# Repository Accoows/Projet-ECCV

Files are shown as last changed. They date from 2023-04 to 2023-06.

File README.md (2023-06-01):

Ce projet est réalisé dans le cadre du module Communication Sans Fil en Licence 1 à l’Université
Nice Sophia Antipolis.

Le projet a été réalisé en groupe avec 3 personnes : Jules; Arthur; Alec

# Projet-ECCV

ProjetECCV

# Description du projet

Il s'agit de créer une voiture télécommandée contrôlée par un smartphone grâce à une application. L'application utilisée, appelée "Blynk", est disponible sur les plateformes IOS et Android. L'utilisateur peut utiliser des sliders pour contrôler les moteurs à l'avant de la voiture, en les déplaçant vers l'avant ou l'arrière individuellement.

L'objectif est d'obtenir une portée de signal supérieure à 20 mètres en utilisant une connexion serveur via 4G entre le système embarqué de la voiture et le smartphone. Cette liaison permettra au smartphone de contrôler la voiture à distance et d'établir une communication fiable sur une distance étendue. Le smartphone envoie les données à un serveur Blynk, qui les transmet ensuite à la carte Wi-Fi pour activer les moteurs. Un système d'historique de connexion est intégré pour suivre la durée pendant laquelle l'engin reste connecté.

BlynkExample

# Matériel utilisé

### Pour réaliser l'engin chenillé, vous aurez besoin des éléments suivants :
- x1 Carte ESP8266 NodeMCU Amica V2 (ESP-12F)
- x1 Un Pont H L298N
- x1 Une breadboard (Cable management)
- x1 Une batterie externe
- x1 Support de piles 12V
- x2 Moteur DC - 12V
- Caisse - Impression 3D
- Roues et Chenilles - Impression 3D
- Des fils
- Du polystyrène

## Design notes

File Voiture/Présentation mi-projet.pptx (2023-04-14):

## Engin CHENILLé CAMPUS VALROSE Présentation de mi-parcours

- Arthur Gonzales
- Alec Passolunghi
- Jules Roy
UE ELECTRONIQUE S2 : Communication sans fil

1

## Objectif du projet

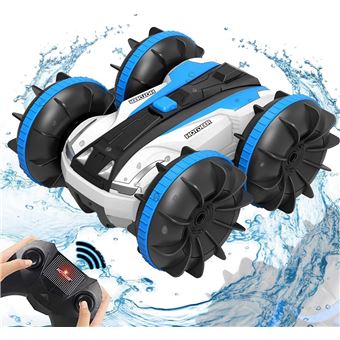
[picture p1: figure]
Voiture Télécommandée Amphibie, Véhicule de Course de Jouet à Haute Vitesse 2.4GHz 4WD, Rotation à 360 degrés, （Bleu） - Voiture télécommandée - Achat & prix | fnac
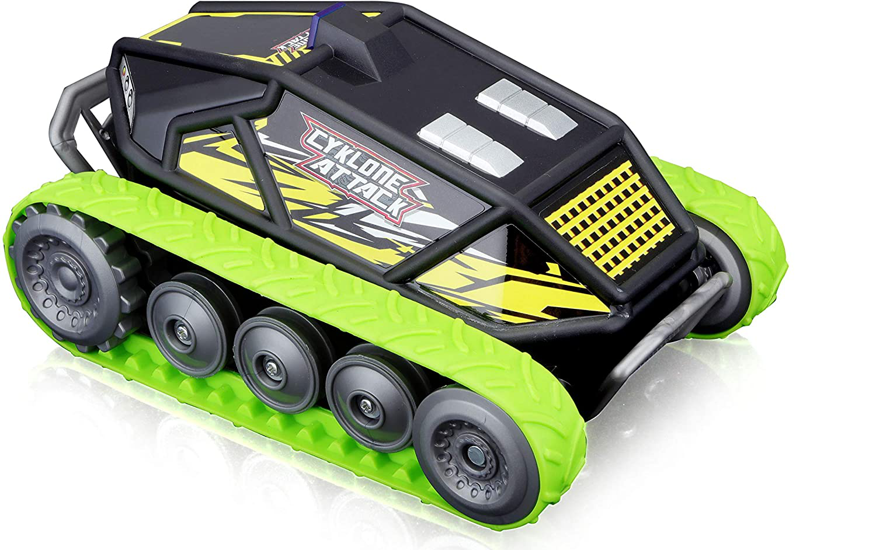
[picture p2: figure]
Bburago Maisto France Véhicule radiocommandé à Chenille Tread Shredder 27 MHz : Amazon.fr: Jeux et Jouets

2

## Répartition des taches et planning

Alec
Modélisation
Arthur
Budget
Programmation
Jules
Documentation
À attribuer
Assemblage
Impression des pièces

14 Avril
Présentation de Mi-projet
Fin Avril
Réception des pièces
30 Mai
Présentation projet final
Montage
Mi Mai
Impression des pièces 3D
Début Mai
Programmation

3

## Résultat attendu

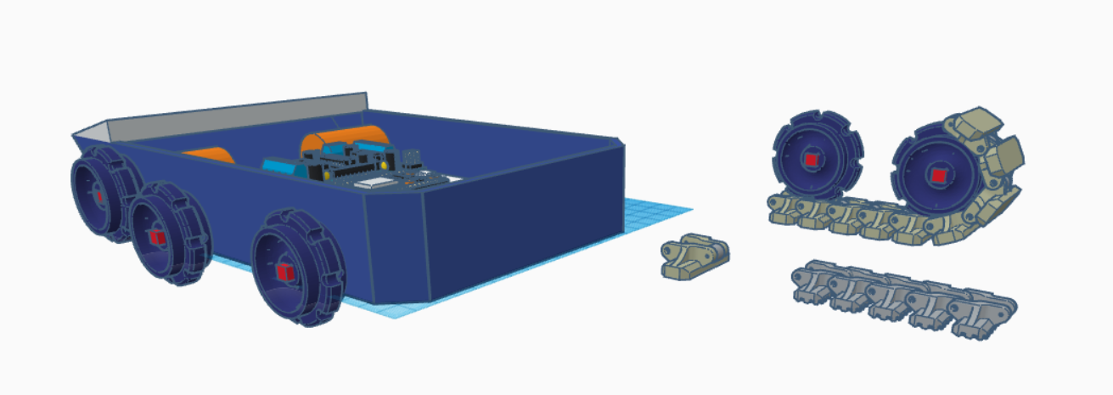
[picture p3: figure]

4

## Méthode de réalisation

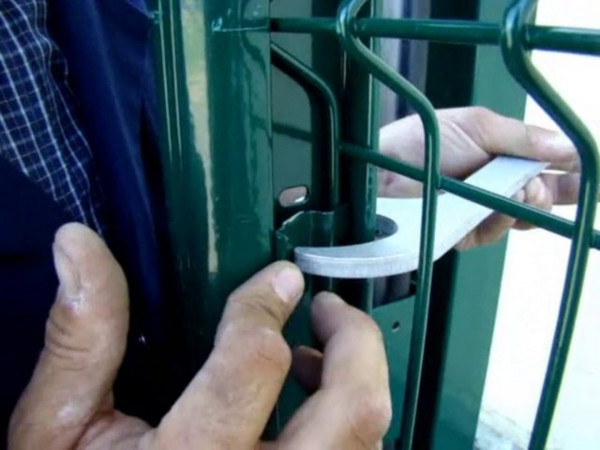
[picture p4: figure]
Clé à Clips, idéal pour le montage de vos clôtures| CLÔTUR-ECO - Clôtur-Éco
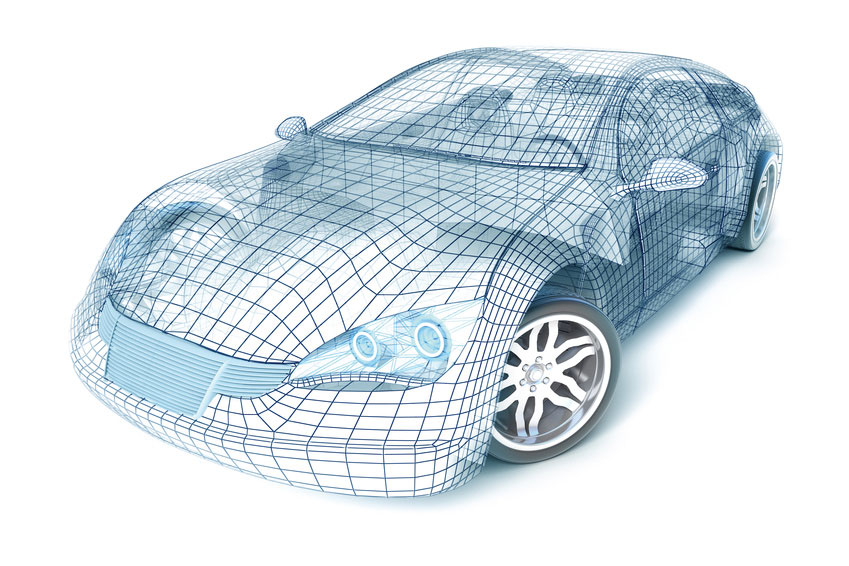
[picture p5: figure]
Comment choisir un logiciel de modélisation 3D ? - F3DF
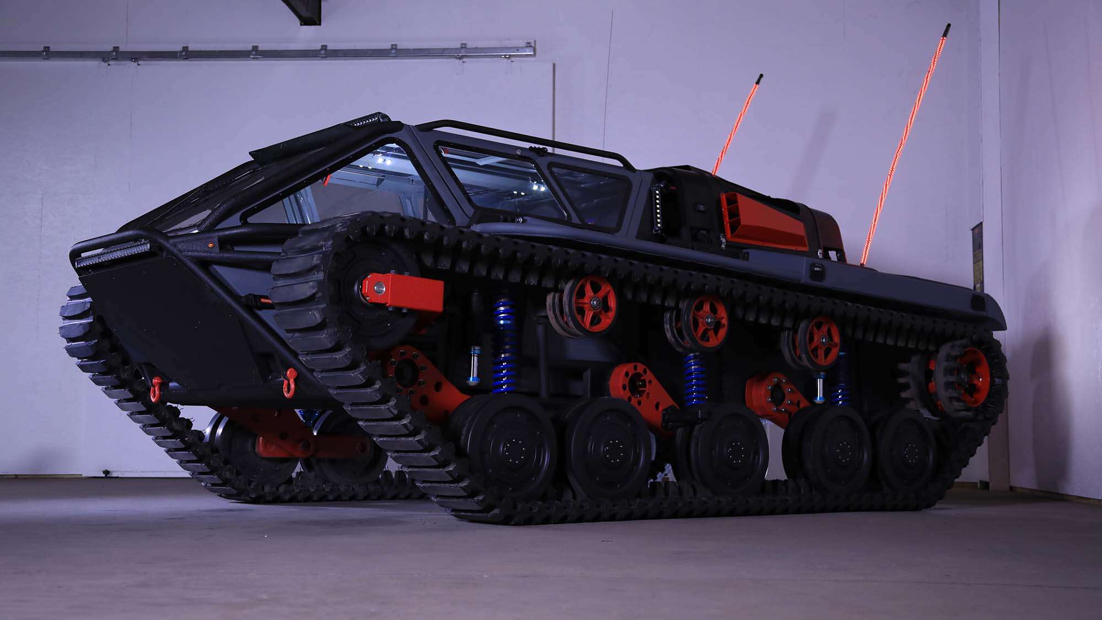
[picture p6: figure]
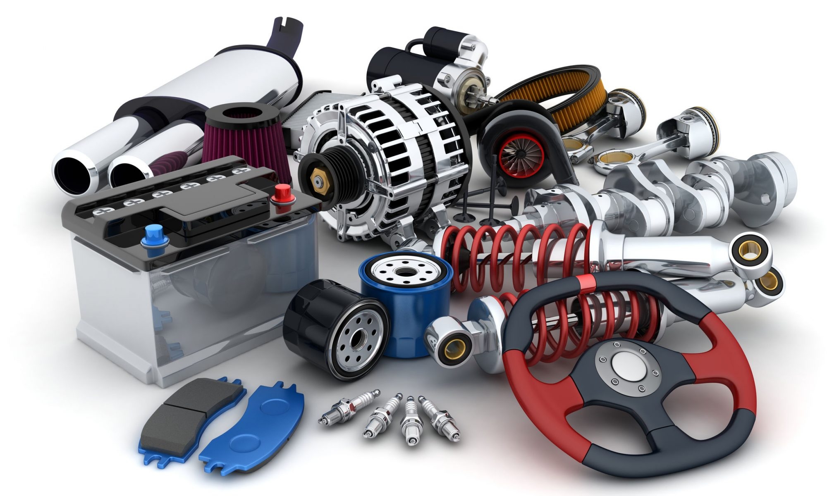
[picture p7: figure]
Enquête - Pièces autos : comment bien les choisir en évitant les pièges
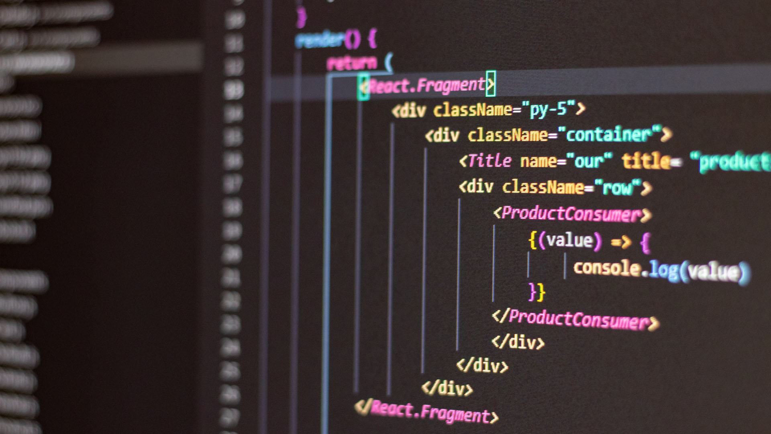
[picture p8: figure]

5

## Moyens nécessaires

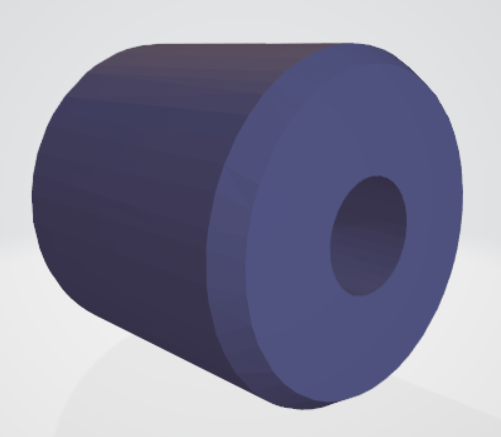
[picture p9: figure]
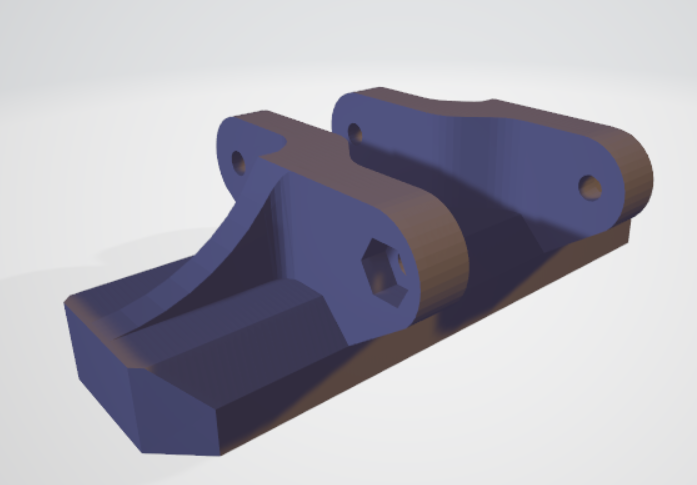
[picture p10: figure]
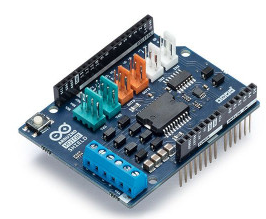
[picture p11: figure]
Arduino Motor Shield 2 x 2 A A000079
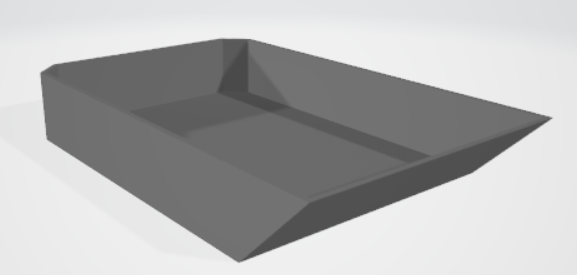
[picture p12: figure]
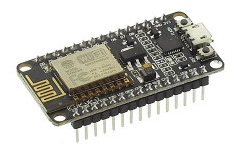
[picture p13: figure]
Module NodeMCU ESP8266
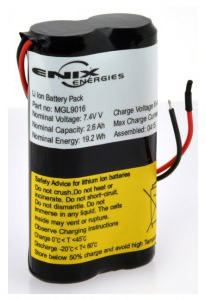
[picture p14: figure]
Accu Li-Ion MGL9016
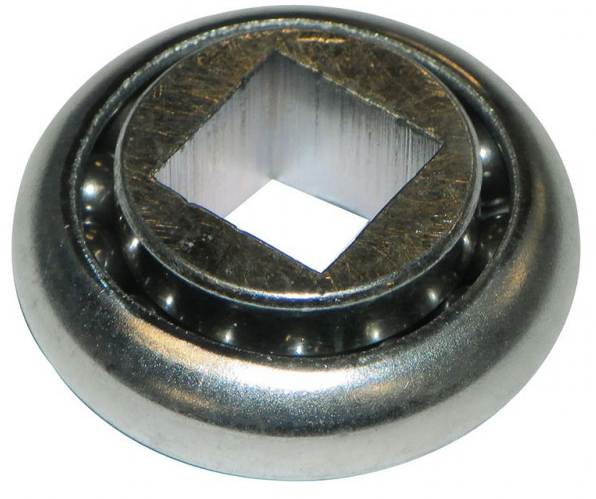
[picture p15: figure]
Roulement à bille 28 mm extérieur et carré de 10 mm - Euromatik
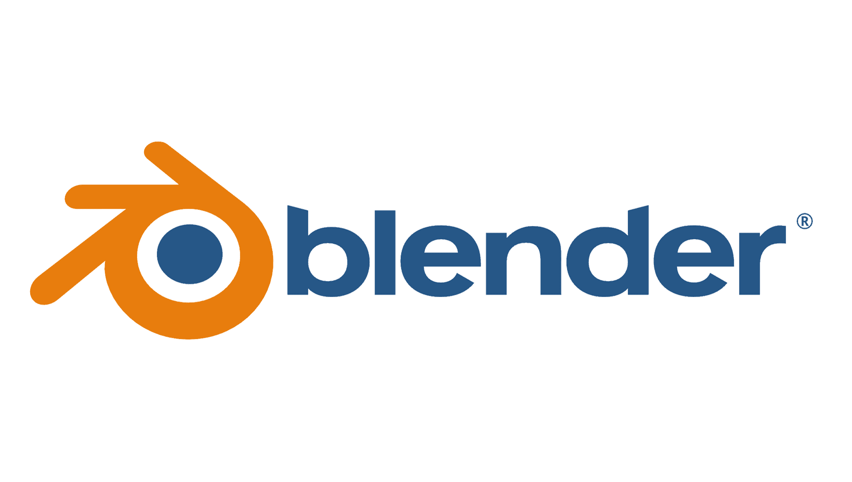
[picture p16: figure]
Blender Logo et symbole, sens, histoire, PNG, marque
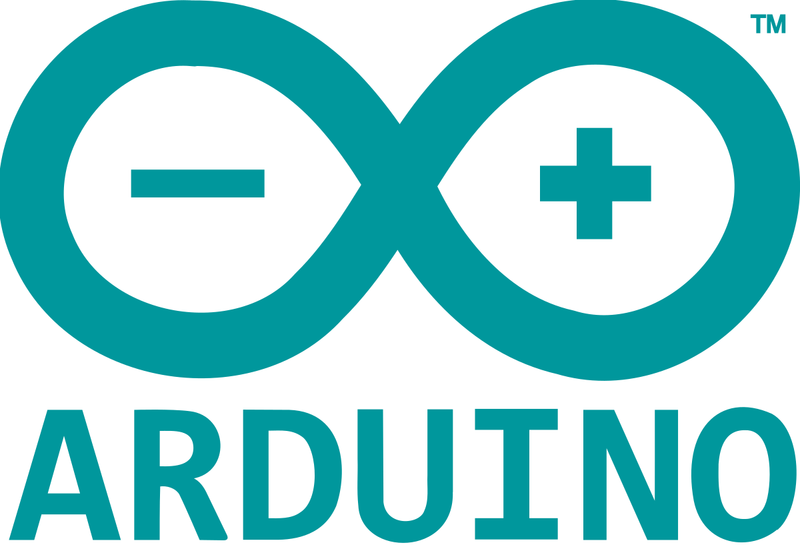
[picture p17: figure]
Arduino — Wikipédia

6

## Difficultés rencontrés

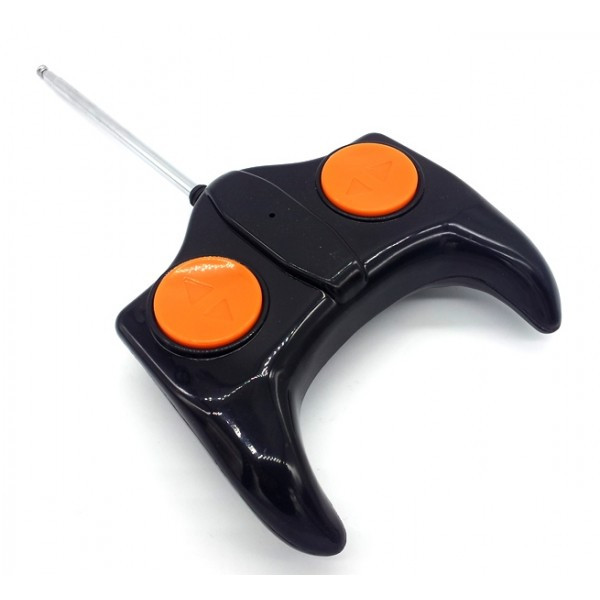
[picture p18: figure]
Télécommande parentale 12V voiture électrique - PitRacing

?

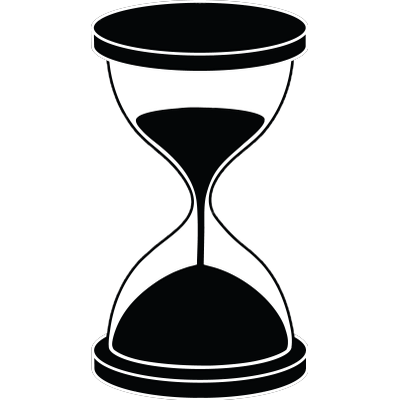
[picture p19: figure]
Sablier Clipart PNG transparents - StickPNG
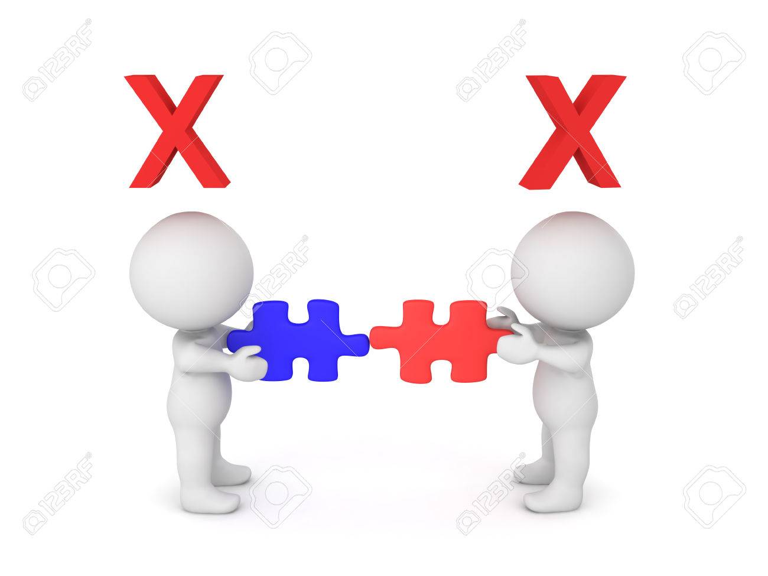
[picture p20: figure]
Deux Personnages 3d Contenant Des Pièces De Puzzle Incompatibles. Symboliser L'incompatibilité D'une Idée Différente. Banque D'Images Et Photos Libres De Droits. Image 75228508.
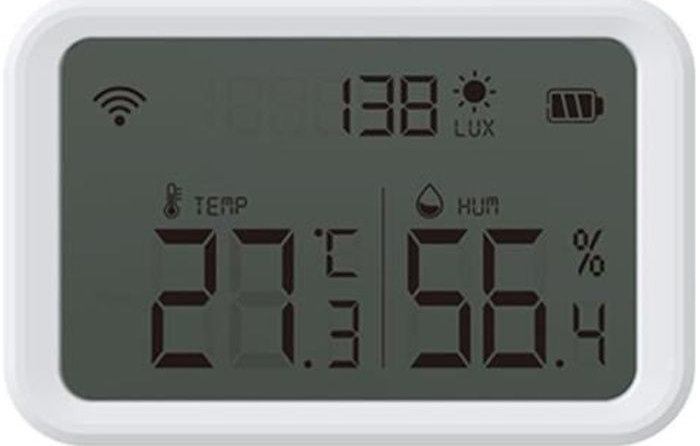
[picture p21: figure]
Tuya Zigbee – capteur de température et d'humidité 3.0, détecteur de lumière Lux, hygromètre, thermomètre, écran [984BC7B] - Cdiscount Bricolage
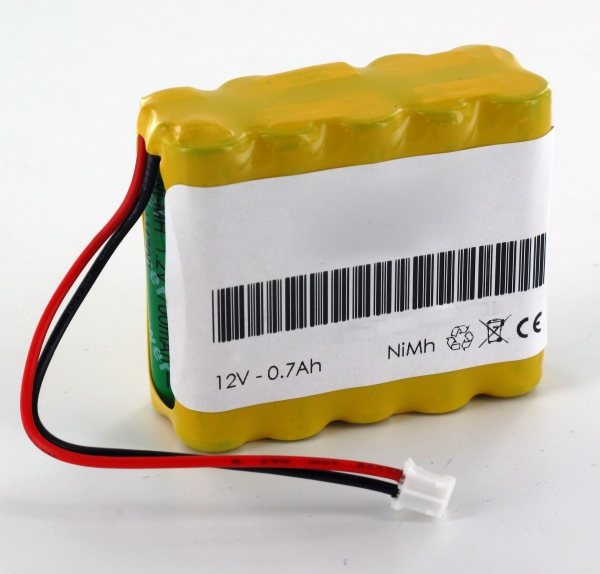
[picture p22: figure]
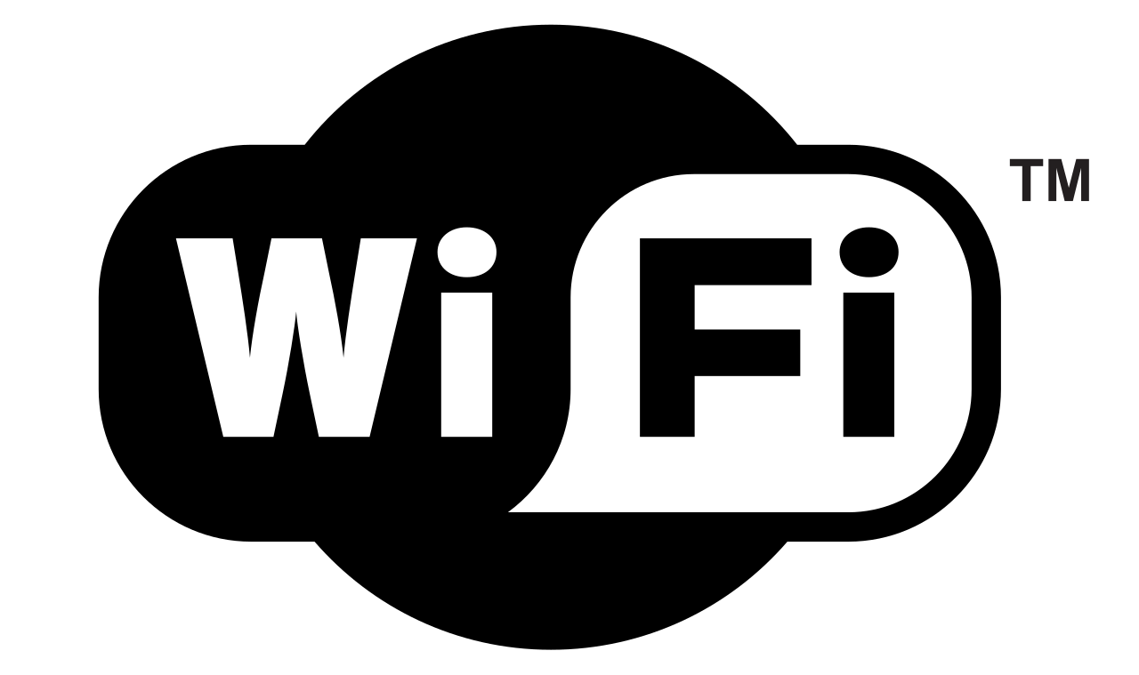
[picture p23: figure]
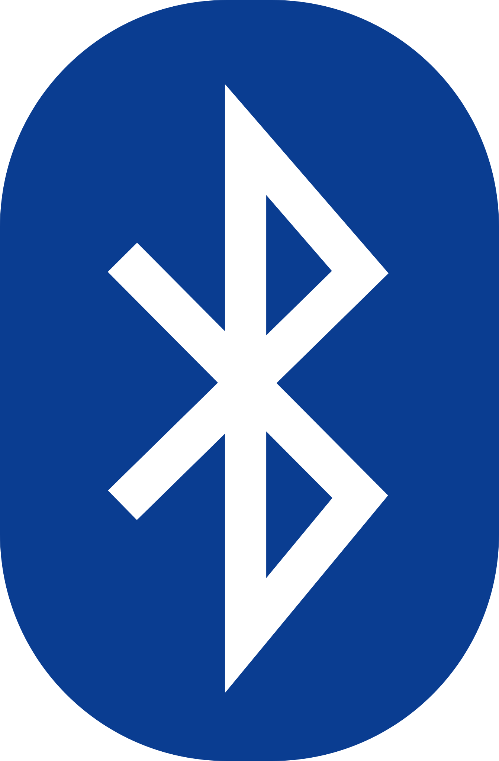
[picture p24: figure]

7

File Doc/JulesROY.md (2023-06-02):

# Cahier de suivi du projet de Jules Roy

* Séance du 17 Mars 2023

Nous avons créé le groupe avec Alec et Arthur. Notre première idée est de créer un engin motorisé télécommandé.
Un tank a l'air assez intéressant.
J'ai proposé de le rendre capable de fonctionner sur l'eau.
Donc pour l'instant on part sur une voiture amphibie.

* Séance du 24 Mars 2023

Nous revoyons la faisabilité du projet.
Alec se penche sur la modélisation du projet. On veut utiliser, pour le déplacement du véhicule, des roues avec des hélices, qui marchent aussi sur l'eau.
On partirait sur une caisse avec quatre roues. Il faudrait deux moteurs, qui chacun engage deux roues.
On se renseigne sur la télécommande. On va sans doute essayer d'utiliser un téléphone, ça a l'air plus cool.
Arthur regarde comment le projet peut fonctionner. De quoi aurait-on besoin?

* Séance du 31 Mars 2023

Nous avons abandonné l'idée de rendre le véhicule amphibie. C'était trop ambitieux.
Après documentation, juste faire un véhicule télécommandé est très compliqué.
Nous allons faire une voiture avec 6 roues et des chenilles. les deux roues avant sont motorisés.
On a décidé d'imprimer les pièces. Alec a déjà presque tous les modèles.
On va utiliser un téléphone pour commander la voiture.
Et on va utiliser une connexion wifi. Même si on a plus vu LoRa en TP, on pense que grace au wifi on aura une plus grande portée de signal.

* Séance du 7 Avril 2023

On a fait un TP sur LoRaWan.

* 11 Avril 2023

Nous avons réalisé le powerpoint pour la présentation de mi-projet.
Nous avons revu le planning et la répartition des tâches.
On a fait le point sur tout le matériel nécessaire.

* Séance du 14 Avril 2023

Nous avons présenter notre projet aux enseignants avec le powerpoint que nous avons réalisé plus tôt.
Nous avons eu de bons retours, les enseignants trouvent notre projet réalisable.
Nous leur avons envoyé un mail pour passer la commande du matériel nécessaire.

* Séance du 25 Avril 2023

Premiére séance au Fablab. On a pu discuter avec Lionel pour l'impression de nos pièces.
On a réussit à imprimer deux chenilles très bien et on a relancé une grosse impression qui dure 40 heures.
On la récupérera la semaine prochaine.

* Séance du 2 Mai 2023

Très décu de ce qu'on trouve.. L'impression s'est très mal passé et on ne peut rien utiliser.
Le fil s'est peut-être coincé? Impossible de savoir.
On relance une impression plus courte qu'on récupéreras la prochaine fois.

* Séance du 9 Mai 2023

L'impression s'est bien passé. On en relance une autre.
On pensait recevoir les pièces commandées mais elles ne sont pas encore arrivées.
Le code est fait, la télécommande (le téléphone) est opérationnel.
Plus qu'à tester lorsque l'on aura le matériel.

* Séance du 16 Mai 2023

Nous avons reçu les pièces. Dans le doute, Arthur les avait commandé aussi donc on les a en double.
Le code ne marche pas de suite donc il faut trouver ce qui ne va pas.
Il reste à imprimer la caisse, les roues et quelques chenilles.
La précédente impression s'est mal passée...
Lionel se propose d'imprimer les pièces à Sophia Antipolis. Très gentil de sa part.

* Séance du 23 Mai 2023

Le code fonctionne ! Nous avons la caisse et il ne nous manque que les roues et quelques chenilles.
Il faut beaucoup de chenilles.
Tout à l'air de fonctionner mais malheuresment on ne peut pas vraiment tester sans les roues.

* Séance du 26 Mai 2023

Tout est là. Tout fonctionne.
Ce serait bien mais malheuresement nous n'avons pas pensé à un gros problème: le poids.
L'engin est trop lourd pour avancer.
En plus les pièces imprimés par Lionel sont moins bien détaillées et s'assemblent un peu moins bien, ce qui n'aide pas beaucoup.
On va essayer de régler ça avant la présentation de fin de projet du 2 Juin.

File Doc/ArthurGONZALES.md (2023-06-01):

### Historique du projet :

Au début du projet, l'objectif était de créer une voiture amphibie. Cependant, après avoir constaté que ce concept n'était pas réalisable, nous avons décidé de nous réorienter vers une idée plus simple et réalisable. Ainsi, le projet est devenu un engin à chenilles télécommandé, l'ECCV. Après avoir confirmé que ce serait le projet final, chacun s'est vu attribuer une tâche. La mienne était de réaliser en partie la programmation/système de l'engin.

### La réalisation du projet s'est déroulée en plusieurs étapes.

### Début le 17 mars

Au cours des premières semaines de préparation du projet, j'ai concentré mes efforts sur la recherche de composants qui répondraient au mieux à nos attentes pour le projet que nous avions imaginé. Tout d'abord, j'ai examiné les fondements du projet et son objectif, qui était de créer un objet ou autre dispositif offrant une connexion radiofréquence. Pour notre utilisation et la polyvalence du système, j'ai choisi une carte WiFi ESP8266. Avec cette carte, nous pouvons créer une télécommande sans fil utilisable par toutes les personnes possédant un smartphone. La seconde carte utilisée simultanément est un pont H L298N, qui, comme son nom l'indique, est un pont H. Cette carte nous permet de régler individuellement la puissance et la vitesse de deux moteurs de manière indépendante, ce qui correspond parfaitement à nos exigences. Les autres composants restent standards, et la conception de la partie en 3D de "l'engin" est réalisée par Alec et Jules.

### À partir du 12 avril environ

Jules, Alec et moi-même avons commencé à réfléchir à la meilleure façon d'utiliser l'ESP8266 afin qu'il soit compatible avec l'utilisation d'un smartphone (comme mentionné précédemment). Après des recherches, nous avons décidé d'adopter un système basé sur Blynk. Il s'agit d'un service web et d'une application permettant de configurer une interface directement sur un appareil connecté afin de contrôler à distance des systèmes. J'ai alors approfondi mes connaissances sur le fonctionnement précis du système Blynk, sur la manière de l'utiliser et de l'intégrer à la carte ESP8266, ainsi que sur la façon de faire fonctionner les moteurs à partir du smartphone. Après de nombreux échecs avec les moteurs et la carte ESP8266, j'ai finalement réussi à obtenir un programme plus ou moins simple et fonctionnel. Les nombreux échecs sont principalement survenus en raison de modules qui n'étaient pas adaptés.
En cherchant, j'ai découvert que le système Blynk pouvait se suffire à lui-même en utilisant le module Blynk-Edgent pour la mise en place d'un réseau Wi-Fi local.

### A partir de mi-mai

Nous avons ensuite réussi à obtenir un système fonctionnel qui correspondait à notre vision du projet. Nous avons continué à optimiser, dans la mesure du possible, le programme Arduino de l'engin chenillé pour qu'il s'exécute correctement. Une fois que le programme Arduino était terminé et fonctionnel, j'ai ajouté des annotations aux endroits intéressants afin de mieux comprendre le fonctionnement du programme. L'assemblage a ensuite été réalisé par Jules, Alec et moi-même, afin de concrétiser enfin la vision du concept initial.

### Problèmes rencontrés

Lors de l'écriture du programme et de l'assemblage des composants, j'ai malheureusement rencontré quelques problèmes, ce qui est courant en programmation. Tout d'abord, parlons du système principal appelé "Blynk". Initialement, j'avais prévu d'utiliser des modules spécialement conçus pour ESP8266 afin d'établir une connexion entre la carte et le serveur Blynk. Cependant, après de nombreuses recherches et des difficultés liées à l'intégration de la bibliothèque Blynk dans l'environnement de développement Arduino IDE, j'ai réalisé qu'un autre système de la bibliothèque Blynk correspondait parfaitement à ma vision du programme. J'ai donc décidé d'utiliser le module appelé "BlynkEdgent". Ce module permet de créer un réseau local sur la carte Wi-Fi, ce qui permet de configurer la carte pour se connecter au serveur.
Le deuxième problème matériel est en réalité dû à un défaut de conception de la carte WiFi ESP8266. Après quelques semaines de développement du programme, des problèmes de soudure sont apparus, tels que des résistances qui se détachent, des pins qui se retirent et même une puce qui s'est détachée. Nous avons donc décidé de commander une nouvelle carte pour remédier à cette mésaventure (en espérant que cela ne se reproduise pas à nouveau...)

### Conclusion

Le projet ECCV était ambitieux dès le départ, mais nous avons réussi à réaliser une partie importante du développement. Malgré le revers lié à la puissance insuffisante des moteurs, le projet reste en grande partie viable, même si certains ajustements devront être effectués. Je pense qu'un temps supplémentaire aurait permis de résoudre une partie substantielle des problèmes restants.

### Arthur GONZALES

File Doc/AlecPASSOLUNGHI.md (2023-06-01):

### Historique du projet :

Au début du projet, l'objectif était de créer une voiture amphibie. 
Cependant, après avoir constaté que ce concept n'était pas réalisable, nous avons décidé de nous réorienter vers une idée plus simple et réalisable. 
Ainsi, le projet est devenu un engin à chenilles télécommandé, l'ECCV. 
Après avoir confirmé que ce serait le projet final, chacun s'est vu attribuer une tâche. 
La mienne était de modéliser les composants nécessaires au projet. Ces modèles devront ultimement être imprimés à l'aide d'imprimantes 3D.

###  Description du modèle :

L'engin est composé d'un châssis de 15 cm par 20 cm, de six roues, de six roulements à billes de 1,4 cm de diamètre, de six axes (pour les roues), de 50 chenilles et de 50 axes de chenilles. 
Le châssis et la base du projet doivent pouvoir contenir les deux moteurs électriques, le module Wi-Fi ESP8266, le pont H et l'alimentation électrique composée de 8 piles AA et d'une batterie portable. 
Il sera finalement imprimé, cependant nous avions tenté d'utiliser une découpeuse laser, mais il s'est avéré impossible de l'utiliser. 
Ensuite, viennent les chenilles et les axes qui vont avec. Ils sont issus d'un modèle 3D créé par Eric Braud (https://www.thingiverse.com/thing:2981163/files), puis modifiés afin de mieux correspondre à nos attentes. 
Les modifications comprennent la réduction de la taille des différentes pièces pour les ramener à 40% de leur taille originale et la simplification des pièces afin de ne pas créer de motifs impossibles à imprimer. 
Enfin, les roues et les axes, pour les premières, sont également issus de la même source que les chenilles et ont subi le même traitement. 
Les seconds ont été modélisés par moi afin de relier les roues au châssis et les deux roues avant aux moteurs.

### Problèmes rencontrés :

Différents problèmes ont été rencontrés, d'abord lors de la phase de modélisation, puis lors de la phase d'impression. 
Pendant la phase de modélisation, les principaux problèmes étaient la taille des composants tels que les moteurs ou les différentes sources d'énergie, ainsi que la connexion entre les modèles 3D des chenilles et des roues avec celui du châssis. 
Par exemple, il était nécessaire de laisser suffisamment d'espace pour que les chenilles ne rentrent pas en contact avec la caisse. 
Enfin, il y avait aussi l'emplacement des roulements à billes qui devait permettre de fixer les moteurs (pour ceux à l'avant) et être suffisamment bas pour que le châssis ne soit pas en contact avec le sol. 
Ensuite, est venue la phase d'impression qui n'a pas été sans quelques échecs. 
Tout d'abord, nous avons dû apprendre à utiliser les logiciels associés aux imprimantes, puis nous avons dû faire face à des impressions ratées, en particulier sur les chenilles et les axes, qui ont dû être modifiés pour faciliter l'impression.
Enfin, il s'est avéré que l'ensemble final était trop massif pour les moteurs électriques dont nous disposions. Si je devais revenir sur le projet, j'opterais pour des moteurs au moins deux fois plus puissants.

### Conclusion :

Le projet ECCV était ambitieux dès le départ, mais nous avons réussi à réaliser une partie importante du développement. Malgré le revers lié à la puissance insuffisante des moteurs, le projet reste en grande partie viable, même si certains ajustements devront être effectués. Je pense qu'un temps supplémentaire aurait permis de résoudre une partie substantielle des problèmes restants.

### Alec Passolunghi

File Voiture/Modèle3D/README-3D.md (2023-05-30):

Les modèles 3D ont étaient réalisés à l'aide de Tinkercad et Blender.

Les fichiers comportent :

- Le concept de tout le projet
- le modèle 3D de la caisse final
- Des pièces divers (axes de roues, axes chenilles)
- Le modèle 3D de la chenille (par ebraud modifié par Alec)
- La roue adapté à la chenille 3D (par ebraud modifié par Alec)

Exploitation de modèle disponible pour la réalisation des chenilles : https://www.thingiverse.com/thing:2981163/files

Les modèles récupérés disponible avec un fichier complet des 3D du créateur ont étaient modifiés pour correspondre à nos attentes
et adapter à nos créations.

Les modèles 3D récupérés sont utilisés uniquements à titre personnel et éducatif (aucun commerce n'est réalisé)

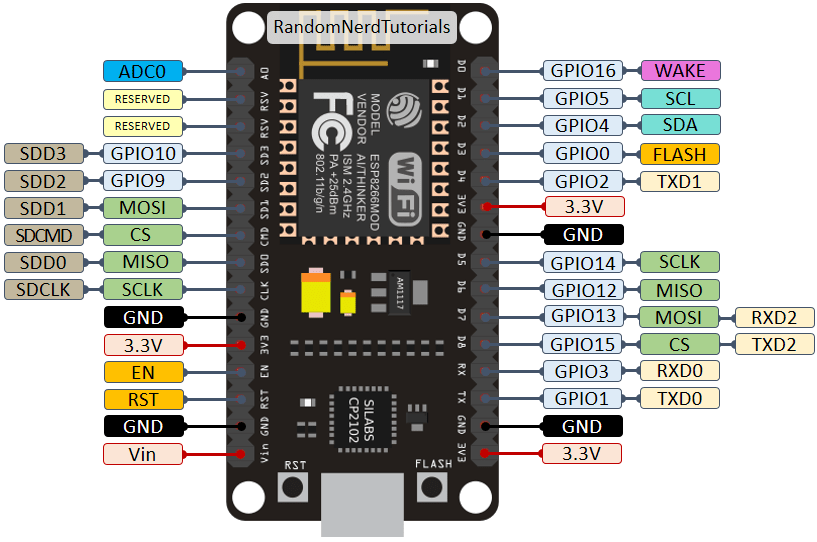
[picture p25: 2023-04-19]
Voiture/Code Arduino/ESP8266KIT.png

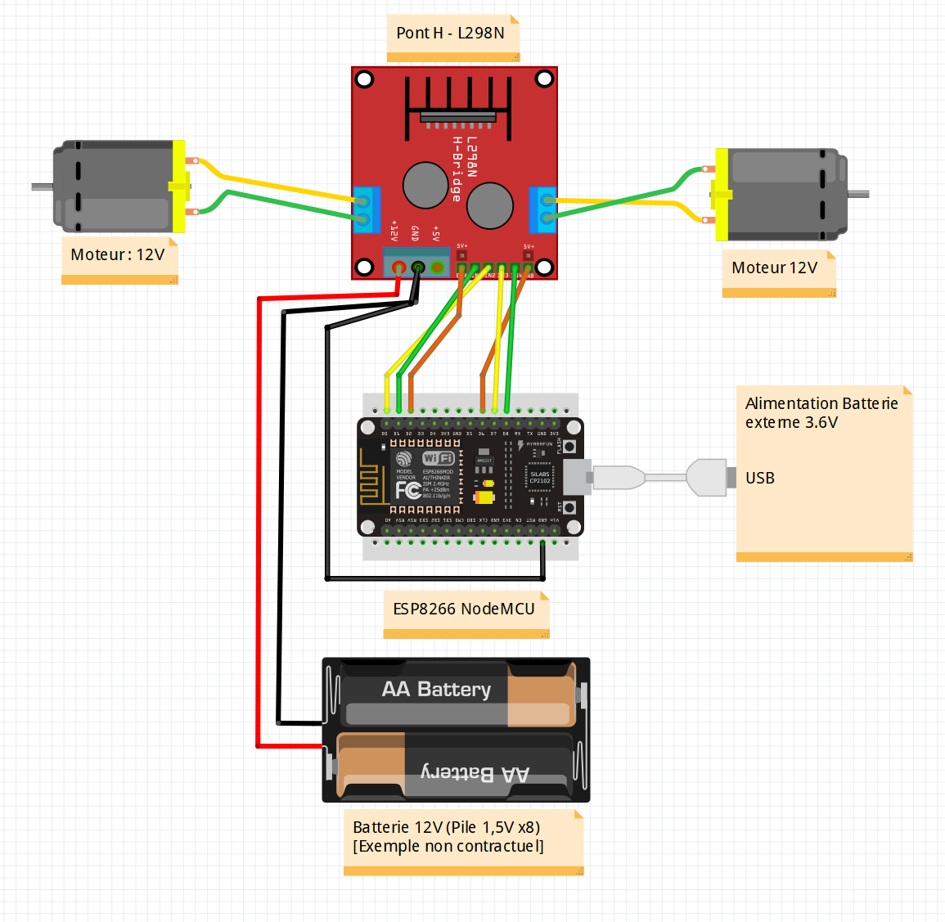
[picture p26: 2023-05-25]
Voiture/Code Arduino/Schéma ECCV Final.png

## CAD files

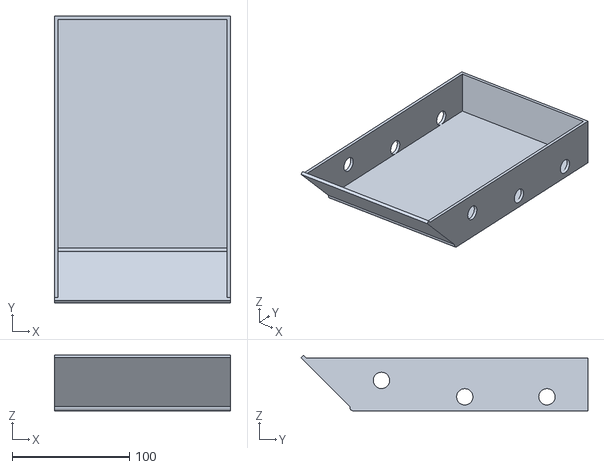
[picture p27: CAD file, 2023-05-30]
Voiture/Modèle3D/eccv caisse mk4.stl
150.0 x 244.5 x 47.5

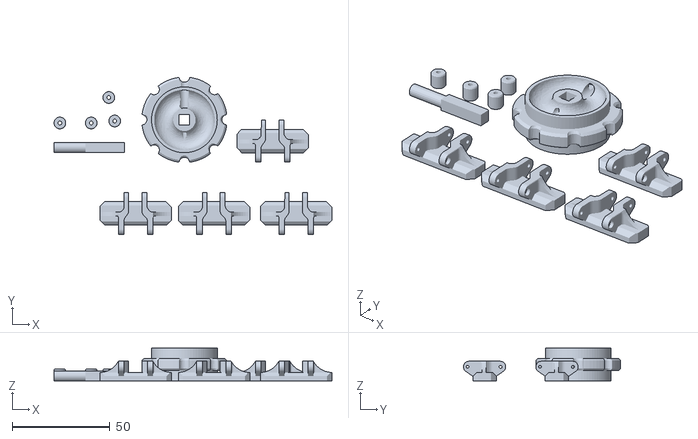
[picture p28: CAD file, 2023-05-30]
Voiture/Modèle3D/petits objets.stl
142.0 x 80.3 x 16.8

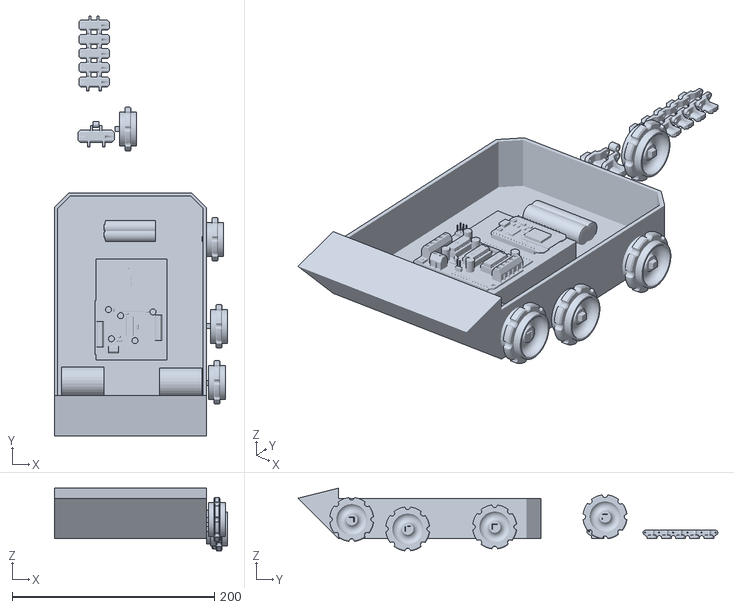
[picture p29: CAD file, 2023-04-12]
Voiture/Modèle3D/Concept 3D.stl
171.0 x 415.0 x 62.0

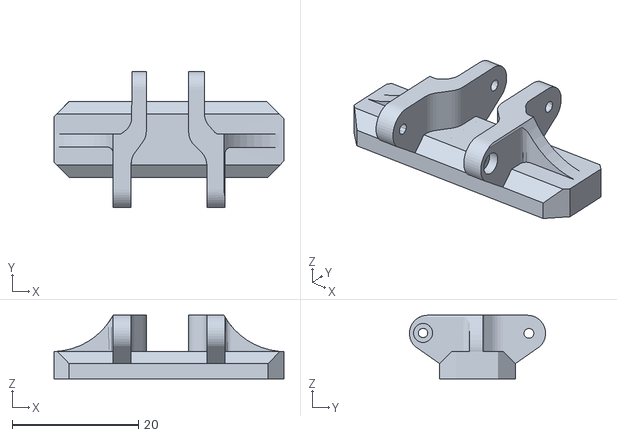
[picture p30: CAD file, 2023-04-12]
Voiture/Modèle3D/Chenille MK2 (Thingiverse - ebraud).stl
36.5 x 21.6 x 10.1

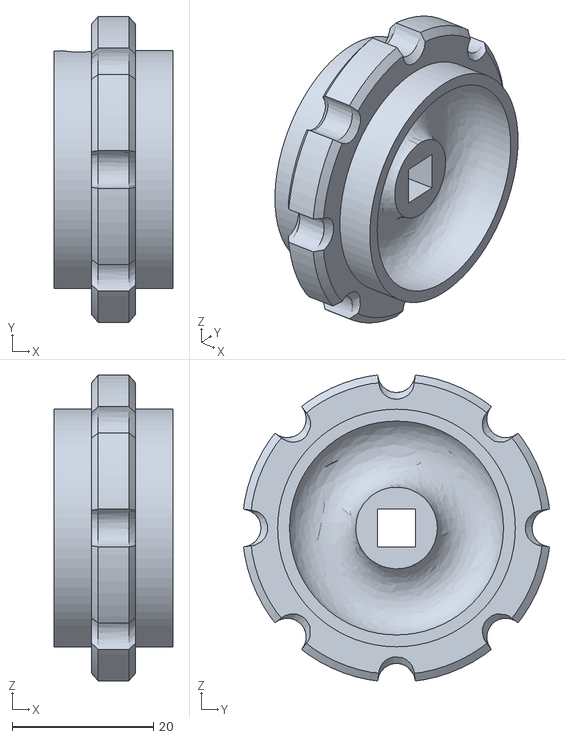
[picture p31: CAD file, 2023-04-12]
Voiture/Modèle3D/Roue MK2 (Thingiverse - ebraud).stl
16.8 x 43.3 x 43.3

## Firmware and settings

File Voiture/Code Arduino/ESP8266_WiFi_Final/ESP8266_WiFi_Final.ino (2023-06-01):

//
//  GitHub ESP8266: https://github.com/esp8266/Arduino
//  ESP8266 Docs: https://arduino-esp8266.readthedocs.io/en/3.1.2/index.html
//  JSON ESP8266 Add: https://arduino.esp8266.com/stable/package_esp8266com_index.json
//  Blynk Library: https://github.com/blynkkk/blynk-library/releases/tag/v1.2.0
//  Blynk Docs: https://docs.blynk.io/en/
//  Docs install: https://www.gotronic.fr/pj2-35754-1803.pdf
//  Tools -> Board -> esp8266 -> NodeMC 1.0 (ESP-12E)
//  Pardon pour le franglais...
// 

// Network Blynk.Cloud
#define BLYNK_TEMPLATE_ID "TMPL59chUkpoO"
#define BLYNK_TEMPLATE_NAME "ECCV Control"

#define BLYNK_FIRMWARE_VERSION "0.1.2"

#define BLYNK_PRINT Serial
#define APP_DEBUG

//Librairy Wifi/Blynk
#include "BlynkEdgent.h"

// Initilisation et création d'un wifi local

// Motor PIN - L298N & ESP8266 (voir ESP8266KIT)

//Motor A (Gauche)
#define ENA 4                // Pin ENA (GPIO4 - D2) (PWM A)
#define speedMotor_A1 5      // Speed Motor A1 (GPIO5 - D1) (IN1)
#define speedMotor_A2 16     // Speed Motor A2 (GPIO16 - D0) (IN2)

//Motor B (Droite)
#define ENB 12               // Pin ENB (GPIO12 - D6) (PWM B)
#define speedMotor_B1 13     // Speed Motor B1 (GPIO13 - D7) (IN3)
#define speedMotor_B2 15     // Speed Motor B2 (GPIO15 - D8)  (IN4)


// Code
// Initialisation des variables de sorties ESP8266 -> L298N
void setup()
{
    //Configure Pins
    pinMode(ENA, OUTPUT); //(ENA - PWM)
    pinMode(ENB, OUTPUT); //(ENB - PWM)
    pinMode(speedMotor_A1, OUTPUT);
    pinMode(speedMotor_A2, OUTPUT);
    pinMode(speedMotor_B1, OUTPUT);
    pinMode(speedMotor_B2, OUTPUT);

    // Speed off
    digitalWrite(ENA, LOW);
    digitalWrite(ENB, LOW);
    
    //Serial communication
    Serial.begin(115200);

    //Connect Blynk Statut
    BlynkEdgent.begin();
}

// SLIDER CONTROLER GAUCHE
BLYNK_WRITE(V0) {
  int speedGauche = param.asInt();                      // Lecture slider Gauche
  Serial.print("Speed Gauche: ");
  Serial.println(speedGauche);
  
  if (speedGauche > 500) {                              //Forward G
    Serial.print("Avant G: ");
    analogWrite(ENA, speedGauche);
    digitalWrite(speedMotor_A1, LOW);
    digitalWrite(speedMotor_A2, HIGH);
  }
  else if (speedGauche < -500) {                        //Backward G
    Serial.print("Arrière G: ");
    analogWrite(ENA,-speedGauche);
    digitalWrite(speedMotor_A1, HIGH);
    digitalWrite(speedMotor_A2, LOW);
  }
  else {                                                //Stop
    Serial.print("Stop G: ");
    analogWrite(ENA, LOW);
    digitalWrite(speedMotor_A1, LOW);
    digitalWrite(speedMotor_A2, LOW);
  }
}

// SLIDER CONTROLER DROITE
BLYNK_WRITE(V1) {
  int speedDroit = param.asInt();                       // Lecture slider Droit
  Serial.print("Speed Droit: ");
  Serial.println(speedDroit);

  if (speedDroit > 500) {                               //Forward D
    Serial.print("Avant D: ");
    analogWrite(ENB, speedDroit);
    digitalWrite(speedMotor_B1, HIGH);
    digitalWrite(speedMotor_B2, LOW);
  }
  else if (speedDroit < -500) {                         //Backward D
    Serial.print("Arrière D: ");
    analogWrite(ENB, -speedDroit);
    digitalWrite(speedMotor_B1, LOW);
    digitalWrite(speedMotor_B2, HIGH);
  }
  else {                                                //Stop
    Serial.print("Stop D: ");
    analogWrite(ENB, LOW);
    digitalWrite(speedMotor_B1, LOW);
    digitalWrite(speedMotor_B2, LOW);
  }
}

//Démarrage du système Blynk
void loop()
{
    BlynkEdgent.run();
}

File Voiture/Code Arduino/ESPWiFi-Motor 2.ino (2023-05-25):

//
//  GitHub ESP8266: https://github.com/esp8266/Arduino
//  ESP8266 Docs: https://arduino-esp8266.readthedocs.io/en/3.1.2/index.html
//  JSON ESP8266 Add: https://arduino.esp8266.com/stable/package_esp8266com_index.json
//  Blynk Library: https://github.com/blynkkk/blynk-library/releases/tag/v1.2.0
//  Blynk Docs: https://docs.blynk.io/en/
//  Docs install: https://www.gotronic.fr/pj2-35754-1803.pdf
//  Tools -> Board -> esp8266 -> NodeMC 1.0 (ESP-12E)
// 

// Network Blynk.Cloud
#define BLYNK_TEMPLATE_ID "TMPL59chUkpoO"
#define BLYNK_TEMPLATE_NAME "ECCV Control"
#define BLYNK_AUTH_TOKEN "PNC5dJ6PvogE40Ot8ako4nH2oXmiATlx"
#define BLYNK_PRINT Serial

//Library WiFi/Blynk
#include <ESP8266WiFi.h>
#include <BlynkSimpleEsp8266.h>

//Auth TOKEN Blynk
char auth[] = BLYNK_AUTH_TOKEN;

//Connection WiFi
char ssid[] = "ECCV-Control";
char pass[] = "ECCV01234";

// Motor PIN Direction
//      TEST
//Motor A
#define directionPin_A 4    // Direction A (GPIO4 - D2) (Shield_D12)
#define speedMotor_A 0      // (Speed) PWM Motor A (GPIO0 - D3) (Shield_D3)
#define brakeMotor_A 2      // Brake Motor A (GPIO2 - D4) (Shield_D9)
//Motor B
#define directionPin_B 12   // Direction B (GPIO12 - D6) (Shield_D13)
#define speedMotor_B 13     // (Speed) PWN Motor B (GPIO13 - D7) (Shield_D11)
#define brakeMotor_B 15     // Brake Motor B (GPIO15 - D8)  (Shield_D8)


//Code
void setup()
{
    //Configure Pins
    pinMode(directionPin_A, OUTPUT);
    pinMode(directionPin_B, OUTPUT);
    pinMode(speedMotor_A, OUTPUT); //(ENA - PWM)
    pinMode(speedMotor_B, OUTPUT); //(ENB - PWM)
    pinMode(brakeMotor_A, OUTPUT);
    pinMode(brakeMotor_B, OUTPUT);

    // Speed off
    digitalWrite(speedMotor_A, LOW);
    digitalWrite(speedMotor_B, LOW);

    Blynk.virtualWrite(V0, 0);
    Blynk.virtualWrite(V1, 0);
    
    //Serial communication
    Serial.begin(9600);

    //Connect Blynk Statut
    Blynk.begin(auth, ssid, pass);
}

// SLIDER CONTROLER GAUCHE
BLYNK_WRITE(V0) {
  int speedGauche = param.asInt(); // lecture slider gauche (Vérifier le [])
  Serial.print("Speed Gauche: ");
  Serial.println(speedGauche); //Affichage valeur G
  if (speedGauche > 500) {                              //Forward G
    analogWrite(speedMotor_B,speedGauche);
    digitalWrite(directionPin_B,HIGH);
    digitalWrite(brakeMotor_B,LOW);
  }
  else if (speedGauche < -500) {                        //Backward G
    analogWrite(speedMotor_B,-speedGauche);
    digitalWrite(directionPin_B,LOW);
    digitalWrite(brakeMotor_B,LOW);
  }
  else {                                                //Stop
    analogWrite(speedMotor_B, 0);
    digitalWrite(brakeMotor_B,HIGH);
  }
}

// SLIDER CONTROLER DROITE
BLYNK_WRITE(V1) {
  int speedDroit = param.asInt(); // lecture slider droit (Vérifier le [])
  Serial.print("Speed Droit: ");
  Serial.println(speedDroit); //Affichage valeur D
  if (speedDroit > 500) {                               //Forward D
    analogWrite(speedMotor_A,speedDroit);
    digitalWrite(directionPin_A,LOW);
    digitalWrite(brakeMotor_A,LOW);
  }
  else if (speedDroit < -500) {                         //Backward D
    analogWrite(speedMotor_A,-speedDroit);
    digitalWrite(directionPin_A,HIGH);
    digitalWrite(brakeMotor_A,LOW);
  }
  else {                                                //Stop
    analogWrite(speedMotor_A, 0);
    digitalWrite(brakeMotor_A,HIGH);
  }
}

//Démarrage du système Blynk
void loop()
{
    Blynk.run();
}

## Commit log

2023-04-12 3D Voiture
    [CRCC chenille MK2.stl, CRCC complet.stl, CRCC roue MK2.stl]
2023-04-12 3D
    Actualisation des modèles 3D, version temporaire.
    [CRCC complet.stl, Caisse partie A mk1.stl, Caisse partie B mk1.stl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]
2023-04-12 3D Actualisation
    [Chenille MK2 (Thingiverse - ebraud).stl, Roue MK2 (Thingiverse - ebraud).stl]
2023-04-12 Create Modèle 3D Complet.stl
    [Modèle 3D Complet.stl]
2023-05-16 Circuit ESP8266 / Motor Shield Rev3
    Circuit temporaire pour réaliser des tests
2023-05-25 File Fritzing
    [ECCV Final.fzz]
2023-06-02 PowerPoint Examen
